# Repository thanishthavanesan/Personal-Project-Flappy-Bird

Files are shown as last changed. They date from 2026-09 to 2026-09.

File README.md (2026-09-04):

# Personal-Project-Flappy-Bird
A custom-built version of Flappy Bird running entirely on an ESP32 — no game engine, no shortcuts, just hardware. It plays on a small OLED screen, keeps score on a separate 4-digit display (driven through a shift register), and you control it with a joystick plus three buttons for flap, pause, and quit.

Most of the work was in the debugging. The score display flickered until I figured out it needed its own hardware timer running in the background, independent of everything else the chip was doing. Scoring itself was buggy too — it kept missing points because it was checking for one exact pixel position instead of just checking whether the pipe had passed. And the shift register wiring didn't match any online tutorial, so I had to test it pin-by-pin myself to figure out the actual order.

Once the breadboard version worked, I also designed and routed a proper PCB for it in KiCad, going through schematic capture, matching footprints, and cleaning it up until it passed all design checks.

Built with: C/C++ (Arduino), ESP32 (GPIO/ADC/I2C), hardware timers, shift register multiplexing, SSD1306 OLED, KiCad.

** KiCad files are named under "Hobbies" folder and .ino file is named under "ThanishThavanesan_flappy_bird **

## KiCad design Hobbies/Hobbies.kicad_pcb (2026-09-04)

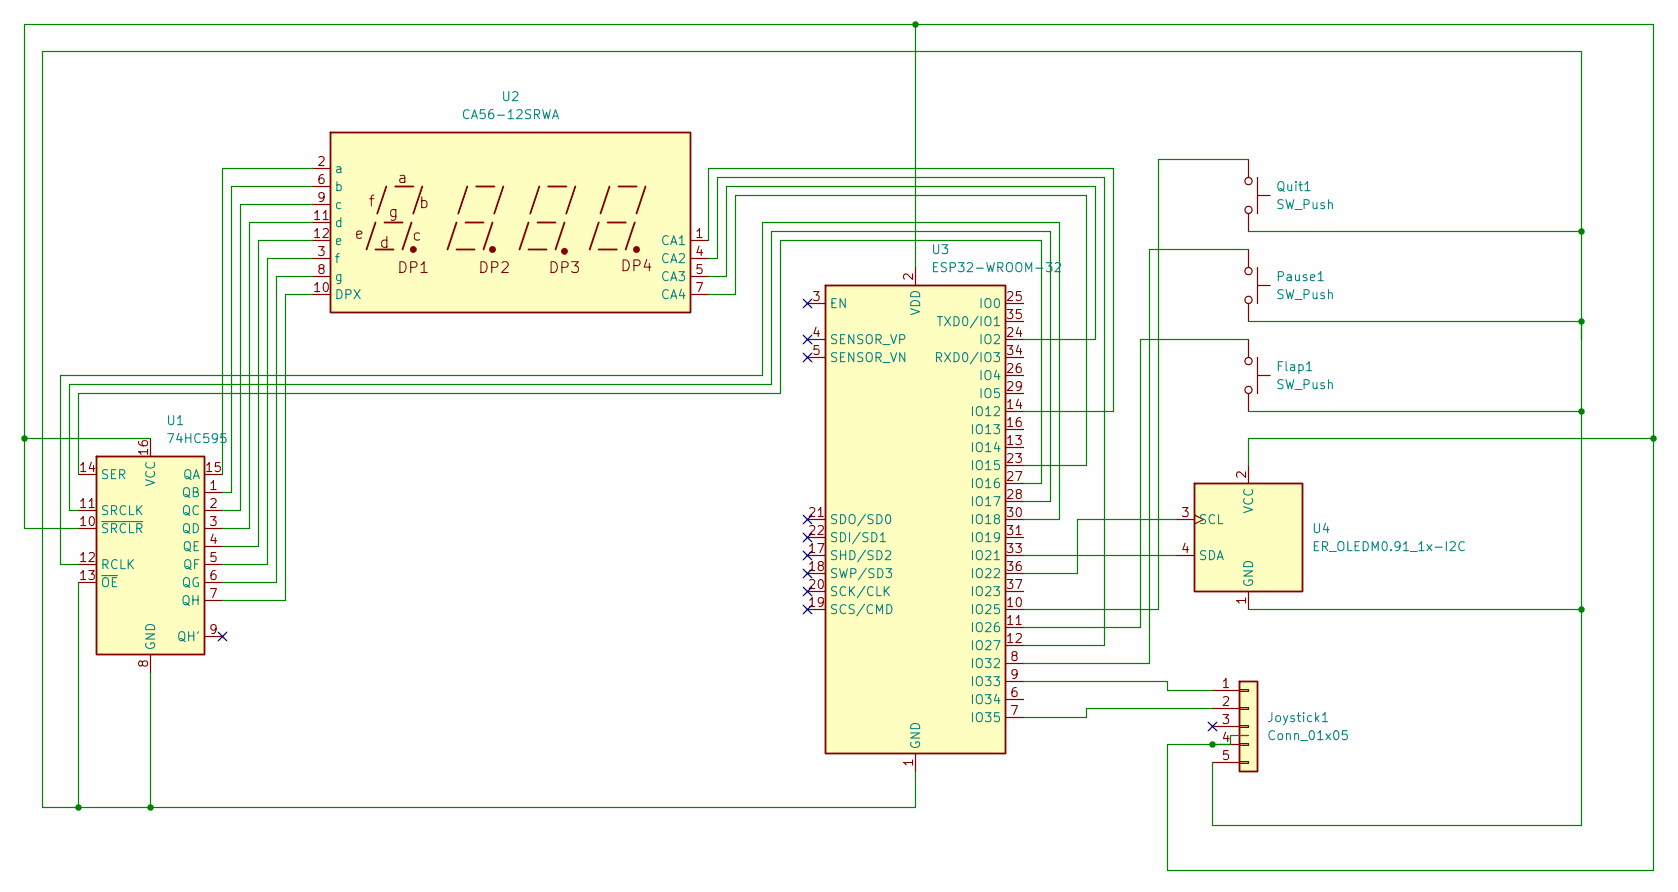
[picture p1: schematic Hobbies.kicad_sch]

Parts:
Flap1: SW_Push; SW_PUSH_6mm
Joystick1: Conn_01x05; PinSocket_1x05_P2.54mm_Vertical
Pause1: SW_Push; SW_PUSH_6mm
Quit1: SW_Push; SW_PUSH_6mm
U1: 74HC595; DIP-16_W7.62mm
U2: CA56-12SRWA
U3: ESP32-WROOM-32
U4: ER_OLEDM0.91_1x-I2C; PinSocket_1x04_P2.54mm_Vertical

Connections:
unnamed: Flap1.2, Joystick1.5 (GND), Pause1.2, Quit1.2, U1.8 (GND), U1.13 (~OE), U3.1 (GND), U3.15 (GND), U3.38 (GND), U3.39 (GND), U4.1 (GND)
unnamed: Joystick1.1 (SW), U3.9 (IO33)
unnamed: Joystick1.4 (VCC), U1.10 (~SRCLR), U1.16 (VCC), U3.2 (VDD), U4.2 (VCC)
unnamed: Joystick1.2 (VRy), U3.7 (IO35)
unnamed: U1.15 (QA), U2.2 (a)
unnamed: U1.1 (QB), U2.6 (b)
unnamed: U1.2 (QC), U2.9 (c)
unnamed: U1.3 (QD), U2.11 (d)
unnamed: U1.4 (QE), U2.12 (e)
unnamed: U1.5 (QF), U2.3 (f)
unnamed: U1.6 (QG), U2.8 (g)
unnamed: U1.7 (QH), U2.10 (DPX)
unnamed: U1.12 (RCLK), U3.30 (IO18)
unnamed: U1.14 (SER), U3.27 (IO16)
unnamed: U1.11 (SRCLK), U3.28 (IO17)
unnamed: U2.1 (CA1), U3.14 (IO12)
unnamed: U2.4 (CA2), U3.12 (IO27)
unnamed: U2.5 (CA3), U3.24 (IO2)
unnamed: U2.7 (CA4), U3.23 (IO15)
unnamed: U3.33 (IO21), U4.4 (SDA)
unnamed: U3.36 (IO22), U4.3 (SCL)
unnamed: Quit1.1, U3.10 (IO25)
unnamed: Flap1.1, U3.11 (IO26)
unnamed: Pause1.1, U3.8 (IO32)

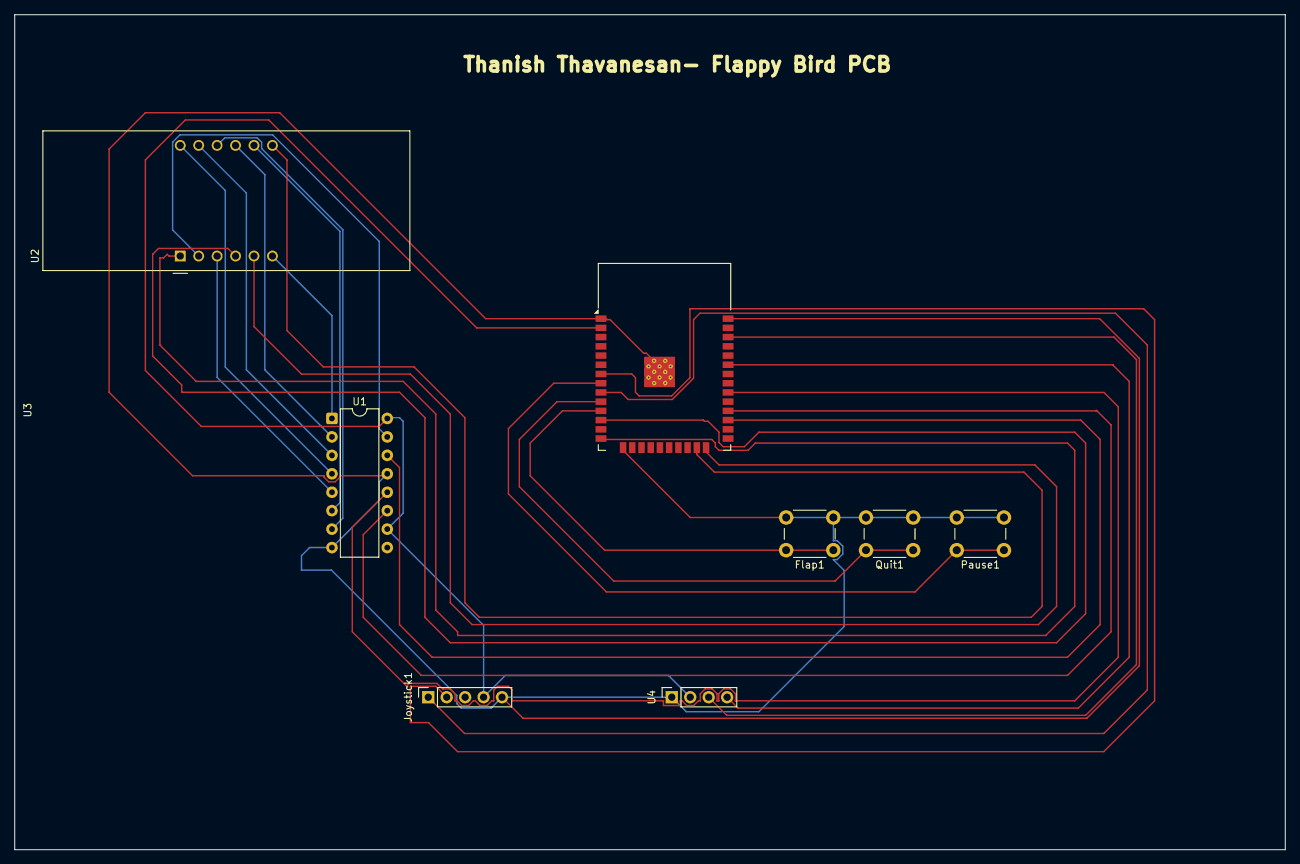
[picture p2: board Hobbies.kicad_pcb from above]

Board: 2 copper layers, 175.0 x 115.0 mm, 8 parts (0 on the bottom side), 24 nets.

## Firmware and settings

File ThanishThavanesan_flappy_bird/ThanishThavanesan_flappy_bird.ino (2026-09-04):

// Thanish Thavanesan
//ESP32 Flappy Bird on OLED screen, Joystick for Menu, and 3-Button Controls
// Controls:
//   Joystick          -> move menu cursor (Easy/Medium/Hard) and tilts up for flaps in-game
//   Joystick click    -> confirm menu selection
//   Flap button       -> alternate way to flap
//   Pause button      -> pause / resume
//   Quit button       -> quit to menu


// Libraries used 
#include <Wire.h>
#include <Adafruit_GFX.h>
#include <Adafruit_SSD1306.h>

// OLED Setup 
#define SCREEN_WIDTH 128
#define SCREEN_HEIGHT 64
#define OLED_RESET -1
Adafruit_SSD1306 display(SCREEN_WIDTH, SCREEN_HEIGHT, &Wire, OLED_RESET);

// Joystick Pins 
#define JOYSTICK_SW 33   // click = confirm
#define JOYSTICK_VRY 35  // Y-axis = menu navigation 

// Buttons 
#define FLAP_BUTTON 26    // flap button, wired to GND (uses internal pull-up)
#define PAUSE_BUTTON 32   // pause / resume
#define QUIT_BUTTON 25    // quit to menu

// 7-Segment Display (via 74HC595) 
#define DATA_PIN 16
#define CLOCK_PIN 17
#define LATCH_PIN 18
#define SEG1_PIN 12
#define SEG2_PIN 27
#define SEG3_PIN 2
#define SEG4_PIN 15
int digitPins[4] = {SEG1_PIN, SEG2_PIN, SEG3_PIN, SEG4_PIN};
// Segment patterns wiring: Q0=dp, Q1=g, Q2=f, Q3=e, Q4=d, Q5=c, Q6=b, Q7=a
const byte digitSegments[10] = {
  0xFC, 0x60, 0xDA, 0xF2, 0x66, 0xB6, 0xBE, 0xE0, 0xFE, 0xF6
};
hw_timer_t *displayTimer = NULL;
volatile int isrDigitIndex = 0;
void IRAM_ATTR onDisplayTimer(); // forward declaration - Arduino's auto-prototyping
                                // can miss IRAM_ATTR functions defined later in the file

// Setting up Game State 
enum GameState { DIFFICULTY_SELECT, PLAYING, PAUSED, GAME_OVER_STATE };
GameState gameState = DIFFICULTY_SELECT;

float pipeSpeed = 2.0;    // pixels per game frame
int gapHeightSetting = 22;
int highScore = 0;

// Menu Navigation 
const char* menuLabels[3] = {"Easy", "Medium", "Hard"};
int menuIndex = 0;
bool joystickNeutral = true; // requires returning to center before next move registers
bool joystickFlapNeutral = true; // requires returning to center before the joystick can flap in-game

// Bird 
float birdY = 32;
float birdVelocity = 0;
const float gravity = 0.5;
const float flapStrength = -3.5;
const int birdX = 20;              //left side of bird
const int birdSize = 3;            //size of the bird, adding with birdx=right size

// Pipes 
const int pipeWidth = 10;
const int numPipes = 3;
const int pipeSpacing = 50;
int pipeX[numPipes];
int pipeGapY[numPipes];
bool pipePassed[numPipes];

// Score 
volatile int score = 0;
bool lastFlapButtonState = HIGH;
bool lastPauseButtonState = HIGH;
bool lastQuitButtonState = HIGH;

void setup() {
  Serial.begin(115200);
  pinMode(JOYSTICK_SW, INPUT_PULLUP); // button reads LOW when pressed
  pinMode(FLAP_BUTTON, INPUT_PULLUP); // dedicated flap button, LOW when pressed
  pinMode(PAUSE_BUTTON, INPUT_PULLUP);
  pinMode(QUIT_BUTTON, INPUT_PULLUP);
  // JOYSTICK_VRY is an ADC input pin, no pinMode needed for analogRead

  pinMode(DATA_PIN, OUTPUT);
  pinMode(CLOCK_PIN, OUTPUT);
  pinMode(LATCH_PIN, OUTPUT);
  for (int i = 0; i < 4; i++) pinMode(digitPins[i], OUTPUT);

  Wire.begin();
  Wire.setClock(400000); // faster I^2C = shorter display.display() blocking time,
                          // which was causing the 7-segment multiplexing to not refresh frequently

  if (!display.begin(SSD1306_SWITCHCAPVCC, 0x3C)) {     //0x3C is the OLED's I^2C address
    Serial.println("OLED init failed");
    while (true);
  }

  // Hardware timer: refreshes one 7-segment digit every 2ms in the background,
  // regardless of what the main loop or OLED are doing (fixes the flicker)
  //Calculation: T= 1/1 000 000Hz=0.000001sec= 1 micro sec and 2000 ticks* 1 micro sec=2000 micro sec= 2ms
  displayTimer = timerBegin(1000000); // 1 MHz tick rate
  timerAttachInterrupt(displayTimer, &onDisplayTimer);
  timerAlarm(displayTimer, 2000, true, 0); // 2000 ticks @ 1MHz = 2ms, auto-reload

  gameState = DIFFICULTY_SELECT;
  drawDifficultyScreen();
}

//Adjusts the rate in which pipes come,and the gap from different difficulties
void applyDifficulty(int index) {
  switch (index) {
    case 0: // Easy
      pipeSpeed = 1.5;
      gapHeightSetting = 28;
      break;
    case 1: // Medium
      pipeSpeed = 2.5;
      gapHeightSetting = 22;
      break;
    case 2: // Hard
      pipeSpeed = 3.5;
      gapHeightSetting = 16;
      break;
  }
  resetGame();
}

//Resets the game and places the bird at its initial position
void resetGame() {
  birdY = 32;
  birdVelocity = 0;
  score = 0;
  gameState = PLAYING;
  joystickFlapNeutral = true;

  for (int i = 0; i < numPipes; i++) {
    pipeX[i] = SCREEN_WIDTH + i * pipeSpacing;                         //Screen width=128, pipeSpacing=60
    pipeGapY[i] = random(10, SCREEN_HEIGHT - gapHeightSetting - 10);   //10 is used so it gives the gap some distance from the top
    pipePassed[i] = false;                                             //Initial state, so bird has not passed any pipes
  }
}

void loop() {

  //Makes sure the button is only pressed once during flaps
  bool flapPressed = (digitalRead(FLAP_BUTTON) == LOW);
  bool flapJustPressed = (flapPressed && !lastFlapButtonState);
  lastFlapButtonState = flapPressed;

  bool pausePressed = (digitalRead(PAUSE_BUTTON) == LOW);
  bool pauseJustPressed = (pausePressed && !lastPauseButtonState);
  lastPauseButtonState = pausePressed;

  bool quitPressed = (digitalRead(QUIT_BUTTON) == LOW);
  bool quitJustPressed = (quitPressed && !lastQuitButtonState);
  lastQuitButtonState = quitPressed;

  if (gameState == DIFFICULTY_SELECT) {
    handleMenuNavigation();
    drawDifficultyScreen();
    delay(20);                          //Wait 20ms for OLED to update screen for menu selection
    return;
  }
  //If game is paused create pause screen, and wait until user chooses an option
  if (gameState == PAUSED) {
    if (pauseJustPressed) {
      gameState = PLAYING;
    } else if (quitJustPressed) {
      gameState = DIFFICULTY_SELECT;
    }
    drawPausedScreen();
    delay(20);
    return;
  }

  if (gameState == GAME_OVER_STATE) {
    bool joyClicked = (digitalRead(JOYSTICK_SW) == LOW);  
    if (quitJustPressed || joyClicked) {                 //Click joystick to exit or exit button
      gameState = DIFFICULTY_SELECT;
    }
    drawGame();
    delay(20);
    return;
  }

  // PLAYING state for buttons 
  if (pauseJustPressed) {
    gameState = PAUSED;
    drawPausedScreen();
    delay(20);
    return;
  }
  if (quitJustPressed) {
    gameState = DIFFICULTY_SELECT;
    delay(20);
    return;
  }
  if (flapJustPressed) {
    birdVelocity = flapStrength;
  }

  // Joystick-up also flaps, but requires returning to
  // Center before it can trigger again, so holding it up doesn't spam flaps
  int flapYVal = analogRead(JOYSTICK_VRY);
  if (joystickFlapNeutral) {
    if (flapYVal > 2900) {     //flaps up, since hardware is opposite
      birdVelocity = flapStrength;
      joystickFlapNeutral = false;
    }
  } else {
    if (flapYVal > 1600 && flapYVal < 2500) {       //Center range of joystick
      joystickFlapNeutral = true;
    }
  }

  // Physics
  birdVelocity += gravity;                //Increases downward velocity of bird
  birdY += birdVelocity;                  //Makes the bird move downward

  //Adds barriers to the bottom and top of the screen
  if (birdY < 0) {
    birdY = 0;                      
    birdVelocity = 0;                 //Can go up to the top, but stops upward movement and game continues
  }
  if (birdY > SCREEN_HEIGHT - birdSize) {
    endGame();
  }

  //Move pipes left, and if they have already passed the screen, move them back to the right with different gaps
  for (int i = 0; i < numPipes; i++) {
    pipeX[i] -= pipeSpeed;            //Moves pipes left

    if (pipeX[i] < -pipeWidth) {     //When the whole pipe has disappeared, not just one edge
      pipeX[i] = SCREEN_WIDTH;
      pipeGapY[i] = random(10, SCREEN_HEIGHT - gapHeightSetting - 10);
      pipePassed[i] = false;          //Reset passed score
    }

    bool withinPipeX = (birdX + birdSize > pipeX[i]) && (birdX < pipeX[i] + pipeWidth);   //Checks horizontal overlap with pipe
    bool withinGap = (birdY > pipeGapY[i]) && (birdY + birdSize < pipeGapY[i] + gapHeightSetting); 
    if (withinPipeX && !withinGap) {
      endGame();
    }

    // Give 1 point when right edge of pipe passes the bird (not when the pipe = bird), which avoids
    // missing an exact-pixel match when pipes move by more than 1px per frame
    if (!pipePassed[i] && (pipeX[i] + pipeWidth < birdX)) {
      score++;
      pipePassed[i] = true;
    }
  }

  drawGame();
  delay(30); 
}

void endGame() {
  if (score > highScore) {
    highScore = score;
  }
  gameState = GAME_OVER_STATE;
}

// 7-Segment Display Functions (run from a hardware timer interrupt) 
// Using common cathode, so bits do not get inverted
void IRAM_ATTR sendSegments(byte segData) {            //Tells display which segments to turn on to make a # 
  digitalWrite(LATCH_PIN, LOW); 
  shiftOut(DATA_PIN, CLOCK_PIN, LSBFIRST, segData);
  digitalWrite(LATCH_PIN, HIGH);
}

void IRAM_ATTR showDigitAt(int position, int number) { //Tells display which physical digit position it should turn on 
  sendSegments(digitSegments[number]);
  for (int i = 0; i < 4; i++) {
      digitalWrite(digitPins[i], (i == position) ? LOW : HIGH);
  }
}

// Display refreshes every 2ms from display timer regardless of what the main loop or OLED is doing 
void IRAM_ATTR onDisplayTimer() {
  int num = score;                      //Make a copy so rest of function works with num
  int digit;
  switch (isrDigitIndex) {
    case 0: digit = (num / 1000) % 10; break;
    case 1: digit = (num / 100) % 10; break;
    case 2: digit = (num / 10) % 10; break;
    default: digit = num % 10; break;
  }
  showDigitAt(isrDigitIndex, digit);
  isrDigitIndex = (isrDigitIndex + 1) % 4;
}

// Reads joystick Y-axis and moves the menu cursor once per flick
void handleMenuNavigation() {
  int yVal = analogRead(JOYSTICK_VRY); // ESP32 ADC range: 0-4095, center approximately 2048

  if (joystickNeutral) {
    if (yVal < 1200) { // Pushed up
      menuIndex = (menuIndex + 1) % 3;
      joystickNeutral = false;
    } else if (yVal > 2900) { // Pushed down
      menuIndex = (menuIndex - 1 + 3) % 3;
      joystickNeutral = false;
    }
  } else {
    // Require it to return near center before allowing the next move
    if (yVal > 1600 && yVal < 2500) {
      joystickNeutral = true;
    }
  }

  if (digitalRead(JOYSTICK_SW) == LOW) {     
    applyDifficulty(menuIndex);
  }
}

void drawDifficultyScreen() {
  display.clearDisplay();
  display.setTextColor(SSD1306_WHITE);
  display.setTextSize(1);
  display.setCursor(15, 0);
  display.println("FLAPPY BIRD");
 
  //Lists Modes of difficulty with a ">" cursor for whichever is selected
  for (int i = 0; i < 3; i++) {
    display.setCursor(10, 16 + i * 12);
    if (i == menuIndex) {
      display.print("> ");
    } else {
      display.print("  ");
    }
    display.println(menuLabels[i]);
  }
  //Shows high score and prints it to the OLED
  display.setCursor(0, 55);
  display.print("High Score: ");
  display.println(highScore);

  display.display();
}
 //Display Pause screen setup
void drawPausedScreen() {
  display.clearDisplay();
  display.setTextColor(SSD1306_WHITE);
  display.setTextSize(1);
  display.setCursor(35, 25);
  display.println("PAUSED");
  display.setCursor(5, 40);
  display.println("Resume/Quit btns");
  display.display();
}
//Display end of game with a summary including highscore, final score, and instructions
void drawGame() {
  display.clearDisplay();
  display.setTextColor(SSD1306_WHITE);

  if (gameState == GAME_OVER_STATE) {
    display.setTextSize(1);
    display.setCursor(20, 15);
    display.println("GAME OVER");
    display.setCursor(20, 28);
    display.print("Score: ");
    display.println(score);
    display.setCursor(15, 40);
    display.print("Best: ");
    display.println(highScore);
    display.setCursor(0, 53);
    display.println("Click/Quit for menu");
    display.display();
    return;
  }

  // Bird's setup in game
  display.fillRect(birdX, (int)birdY, birdSize, birdSize, SSD1306_WHITE);

  // Pipe's setup in game
  for (int i = 0; i < numPipes; i++) {
    display.fillRect(pipeX[i], 0, pipeWidth, pipeGapY[i], SSD1306_WHITE);
    display.fillRect(pipeX[i], pipeGapY[i] + gapHeightSetting, pipeWidth, SCREEN_HEIGHT - (pipeGapY[i] + gapHeightSetting), SSD1306_WHITE);
  }

  display.display();
}

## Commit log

2026-09-04 Add ino file and KiCad project
    [Hobbies.kicad_pcb, Hobbies.kicad_sch]
2026-09-04 Update README with KiCad and .ino file details
    Added information about KiCad files and .ino file location.
